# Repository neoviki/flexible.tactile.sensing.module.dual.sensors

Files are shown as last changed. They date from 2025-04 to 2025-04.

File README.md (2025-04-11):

# Flexible Tactile Sensing Module with Dual Sensors

## Description

This project features a **flexible tactile sensing module** equipped with **dual pressure sensors** designed to measure **tactile interaction**, specifically the pressure exerted by external forces. At the core of the module are two **BMP384 barometric pressure sensors** — MEMS (Micro-Electro-Mechanical Systems) sensors capable of measuring both **barometric pressure** and **temperature** with low power consumption. Their sensitivity makes them well-suited for tactile feedback and subtle pressure variation detection.

The **spacing between the two BMP384 sensors** is **3 millimeters**, allowing for localized differential pressure sensing. Both sensors communicate via the **I2C protocol**, ensuring straightforward integration with microcontroller boards such as the **Arduino Due**. The module operates at **3.3V**, and each sensor is assigned a unique I2C address to enable communication on the same bus:

- **Top Sensor**: `0x77`  
- **Bottom Sensor**: `0x76`

This tactile sensing module can be used in robotics, prosthetics, and human-machine interaction applications.

The **sensor module** is designed on a **flexible PCB**, making it adaptable to a wide range of environments where flexibility is essential. The design is created using **Eagle 7.7**, and the board is populated using **surface-mount technology (SMT)**. After population, the board has been tested with an **Arduino Due** to verify its sensor performance and sampling rate for tactile sensing applications.

## Project Structure

```
README.md
01.Documents                            # Essential documents used for this project
02.Schematics.and.Board.Layout.Design   # Contains the schematics and board layout files
03.Manufacturing                        # Contains CAM, DRU files, and other essential files for manufacturing
04.Populated.Board.Testing              # Contains Arduino code to test the tactile sensing module after population
05.Images                               # Contains a list of images
```

### Images

Here are some images related to the project, demonstrating the design and testing process:

1. **Populated Flexible Tactile Sensing Module**  
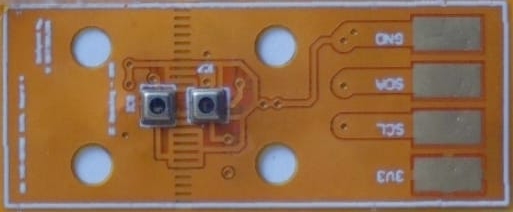
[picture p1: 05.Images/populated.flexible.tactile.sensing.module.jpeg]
Populated Flexible Tactile Sensing Module
   

2. **Board Layout**  
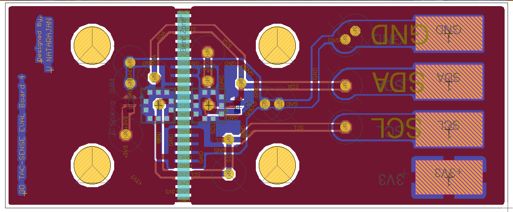
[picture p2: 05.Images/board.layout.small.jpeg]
Board Layout
   

3. **Schematics**  
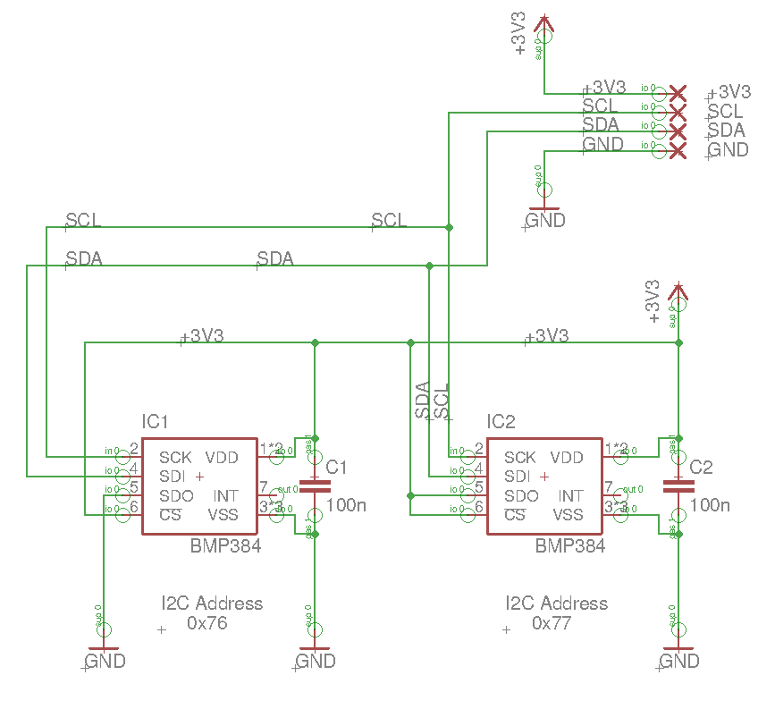
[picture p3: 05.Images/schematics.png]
Schematics
   

4. **Fabricated Flexible PCB**  
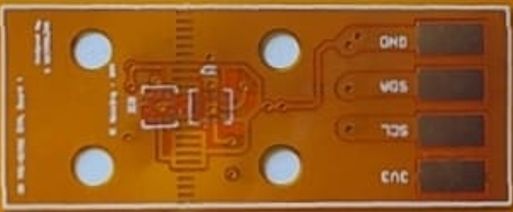
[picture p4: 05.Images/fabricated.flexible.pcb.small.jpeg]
Fabricated Flexible PCB
   

---

## License

This project is licensed under the **BSD 2-Clause License**.  
See the [`LICENSE`](LICENSE) file for full license text.

## Usage and Attribution

You are welcome to **use, modify, or build upon this design** for personal, academic, or commercial purposes.  
If you use or adapt any part of this work, **please credit the original author**:

**V. Natarajan**

For academic usage, you may cite this repository using the following BibTeX entry:

```bibtex
@misc{vnatarajan_flexible_tactile_sensing_module_dual_sensors,
  author       = {V. Natarajan},
  title        = {Flexible Tactile Sensing Module with Dual Sensors},
  year         = {2025},
  howpublished = {\url{https://github.com/neoviki/flexible.tactile.sensing.module.dual.sensors}},
  note         = {Accessed: 2025-04-11}

}
```

> 📎 Attribution helps support and recognize open-source contributions — thank you!

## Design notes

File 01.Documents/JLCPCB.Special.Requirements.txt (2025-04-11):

Please note that the stiffener area is defined in the `Stiffener_Bottom` layer. This layer includes drill holes that should be included in the stiffener material.

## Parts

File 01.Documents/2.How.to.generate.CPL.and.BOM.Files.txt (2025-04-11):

https://jlcpcb.com/help/article/82-How-to-generate-BOM-and-CPL-from-Eagle-CAD-automatically

Board Layout:
	1. File -> Run ULP
	2. Select File "jlcpcb_smta_exporter_v7.ulp"
	3. Select Top Layer -> Select a new folder -> Okay
	4. Again follow step 1 to 3 for bottom layer
	5. Both BOM and ULP will be generated

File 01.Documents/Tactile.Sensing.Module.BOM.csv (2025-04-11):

Part | Value | Device | Package | Description
C1 | 100n | C-EUC0201 | C0201 | CAPACITOR, European symbol
C2 | 100n | C-EUC0201 | C0201 | CAPACITOR, European symbol
I2C |  | PINHD-1X4/90 | 1X04/90 | PIN HEADER
IC1 | BMP384 | BMP384 | BMP384
IC2 | BMP384 | BMP384 | BMP384

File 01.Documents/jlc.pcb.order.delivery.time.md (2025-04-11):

Ordered after all comments 22 July 20XX
Delivery date August 1 20XX 
Time to Delivery from order = 10 days

Cheapest shipping with customs tax paid by JLC
[EuroPacket shipping service ]

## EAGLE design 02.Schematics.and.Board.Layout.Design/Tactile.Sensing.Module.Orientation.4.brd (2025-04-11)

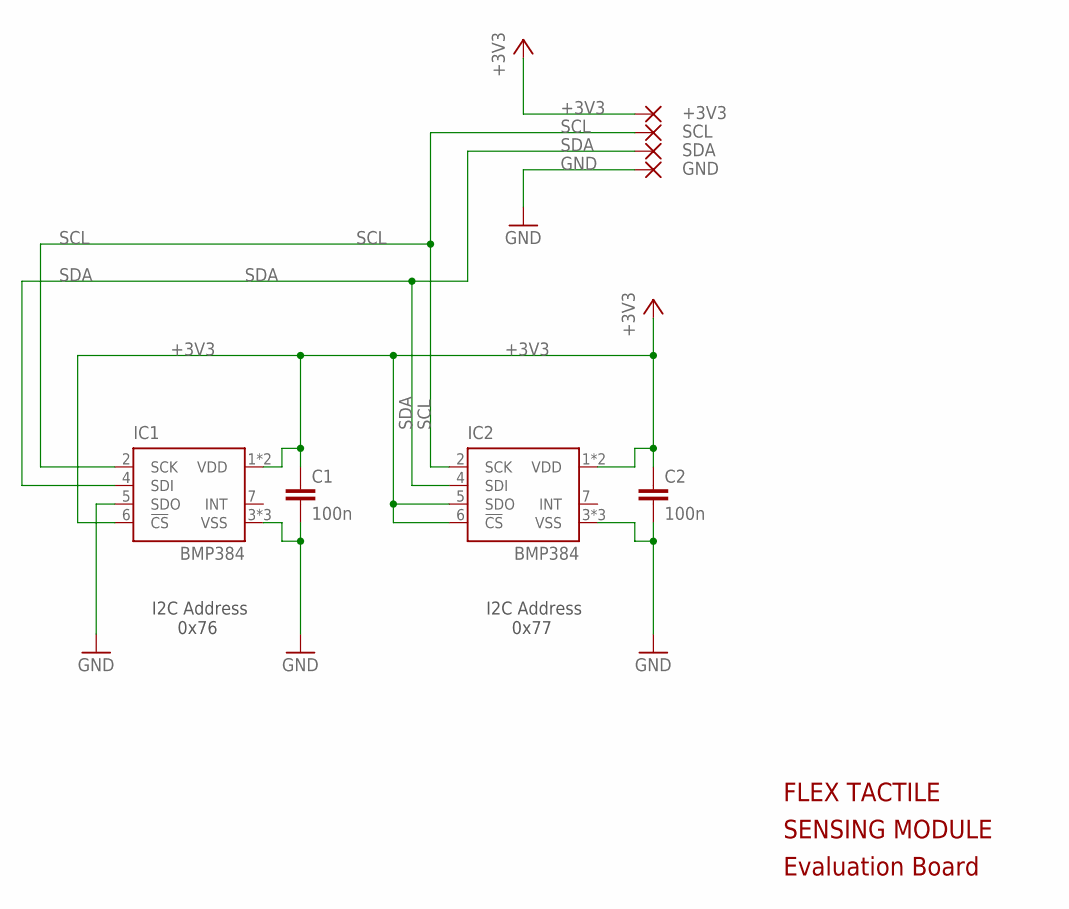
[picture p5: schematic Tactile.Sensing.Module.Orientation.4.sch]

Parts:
+3V3: SMD-PAD-2MMX4MM
C1, C2: 100n; C0201
GND: SMD-PAD-2MMX4MM
IC1, IC2: BMP384
SCL: SMD-PAD-2MMX4MM
SDA: SMD-PAD-2MMX4MM

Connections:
+3V3: +3V3.1, C1.1, C2.1, IC1.1 (VDD), IC1.6 (!CS), IC1.10 (VDD), IC2.1 (VDD), IC2.5 (SDO), IC2.6 (!CS), IC2.10 (VDD)
GND: C1.2, C2.2, GND.1, IC1.3 (VSS), IC1.5 (SDO), IC1.8 (VSS), IC1.9 (VSS), IC2.3 (VSS), IC2.8 (VSS), IC2.9 (VSS)
SCL: IC1.2 (SCK), IC2.2 (SCK), SCL.1
SDA: IC1.4 (SDI), IC2.4 (SDI), SDA.1

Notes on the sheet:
I2C Address 0x77
I2C Address 0x76
SENSING MODULE
Evaluation Board
FLEX TACTILE

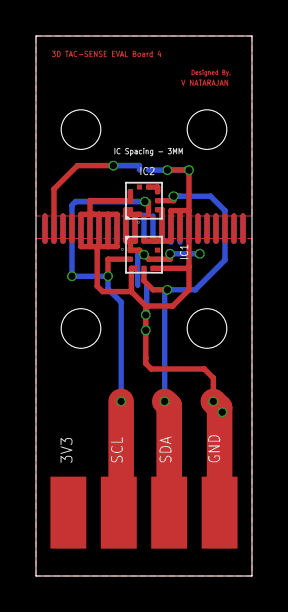
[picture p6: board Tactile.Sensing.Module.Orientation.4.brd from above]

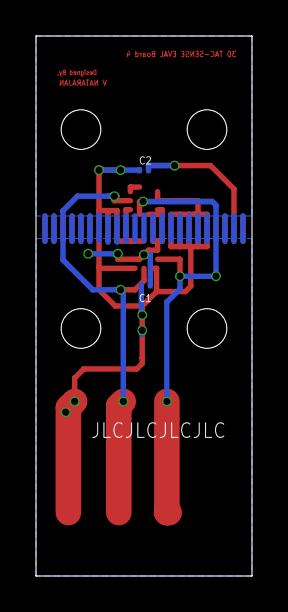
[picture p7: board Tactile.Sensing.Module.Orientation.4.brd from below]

Board: 2 copper layers, 12.0 x 30.0 mm, 8 parts (2 on the bottom side), 4 nets.

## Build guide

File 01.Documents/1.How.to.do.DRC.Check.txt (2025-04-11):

DRC -> load -> jlcpcb-2layers.dru

Check

it is typically done at the board layout

Also need to do the following to avoid stop mask error in DRC

DRC->Mask->limit
Limit: 0.004mm
Stop Min: 0.001mm
Stop Max: 0.004mm
% : 100

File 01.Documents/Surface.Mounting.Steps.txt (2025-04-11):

220 degrees, 13 percent air flow,

30 cm 60 sec
15 cm 30 sec
10 cm 30 sec
4 cm 30 sec
reverse the step, solder will be intact, circular motion

tin bot the componebnt and board

Solder paste I used:

	1. SN42BI58/T3 ( Mildly Rad-Active  - Carful while using )

I can see the same solder paster (1) in the market by EDSYN CR11 ( same SN42BI58 composition ), Melting temperature = 215 to 260 degrees, Wow. It cost 23.99 Euro in reichelt.de

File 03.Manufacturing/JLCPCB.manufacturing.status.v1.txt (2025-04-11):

Text is not visible

1. On Flex PCB, JCL is not able to print text smaller than 0.6096. Your text should be 0.6096 or bigger.
2. They forget to add stiffener
3. The fiber glass panel stiffener cutout is wrong

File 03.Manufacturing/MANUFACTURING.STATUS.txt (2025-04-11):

Manufactured the flex PCB, Populated the tactile sensing module and tested successfully.

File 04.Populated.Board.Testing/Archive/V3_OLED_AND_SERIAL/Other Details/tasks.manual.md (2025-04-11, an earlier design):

Arduino Search library u8g2 and install

- u8g2 by oliver

Tools -> Board -> Board Manager -> Install Arduino SAM Boards ( this is for Arduino Due )

Select Arduino Due Programming Port ( The usb port next to the DC Barrel Jack )

Tools -> Board -> Arm 32 Board -> Arduino Due Programming port

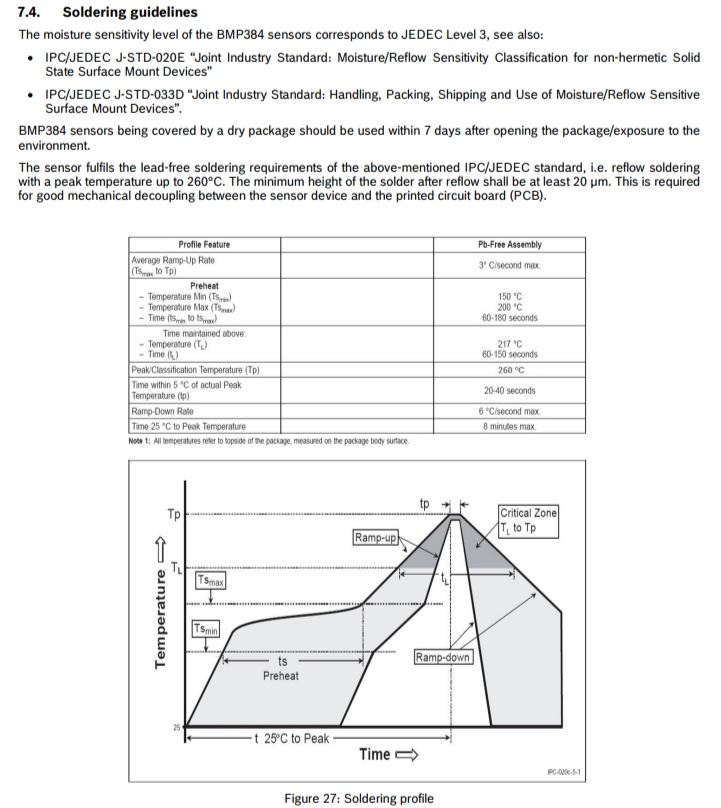
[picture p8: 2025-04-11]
01.Documents/BMP384.Soldering.Handy.Information/Soldering Temperature Profile 1.png

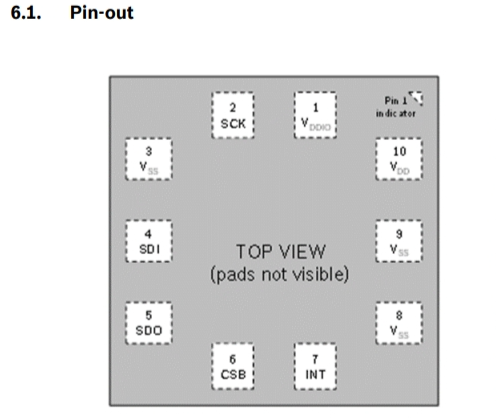
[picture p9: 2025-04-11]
01.Documents/BMP384.Soldering.Handy.Information/BMP384 Top View.png

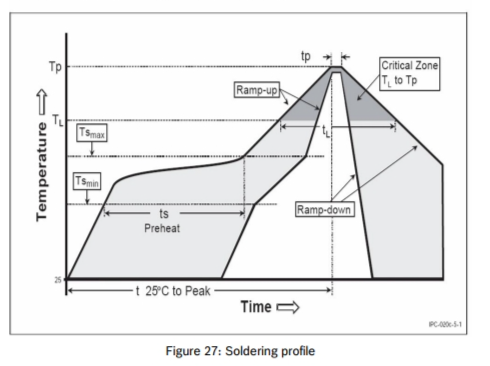
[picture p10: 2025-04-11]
01.Documents/BMP384.Soldering.Handy.Information/Soldering Temperature Profile 3.png

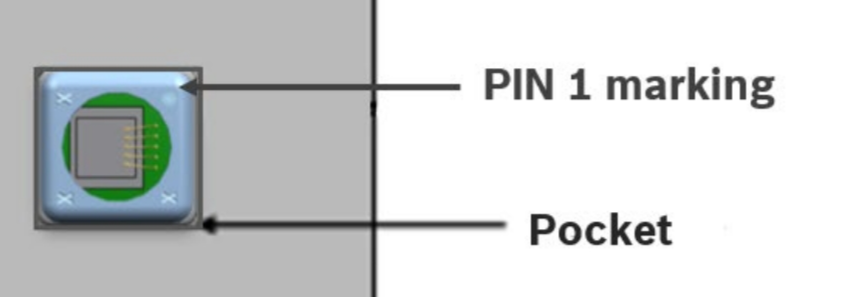
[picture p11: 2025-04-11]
01.Documents/BMP384.Soldering.Handy.Information/BMP384 Top View - Pin 1 Marking.png

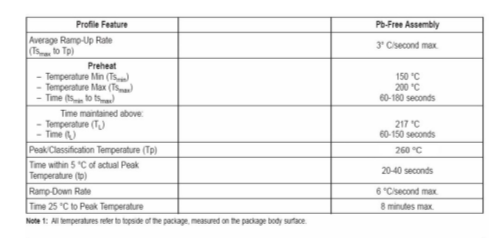
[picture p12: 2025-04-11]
01.Documents/BMP384.Soldering.Handy.Information/Soldering Temperature Profile 2.png

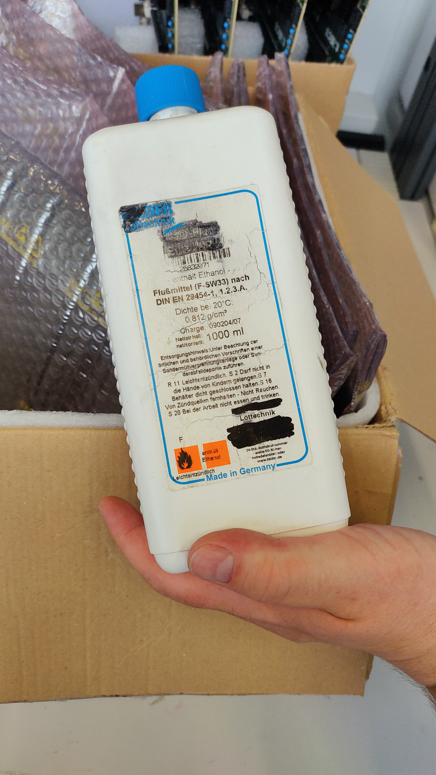
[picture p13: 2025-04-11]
01.Documents/Surface.Mounting.Equipments.Used.Images/solder flux liquid1.jpg

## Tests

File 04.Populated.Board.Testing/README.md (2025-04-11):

Arduino DUE is used to test the populated board. I made a custom board to test with OLED display. 
You can use the sketch/sketch.ino to test the populated board.

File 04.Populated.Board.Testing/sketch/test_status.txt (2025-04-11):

/*

Tested: the code works for my flex PCB on arduino Due

*/

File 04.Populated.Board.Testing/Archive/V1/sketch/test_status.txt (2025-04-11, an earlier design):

/*

Tested: the code works for my flex PCB on arduino Due

*/

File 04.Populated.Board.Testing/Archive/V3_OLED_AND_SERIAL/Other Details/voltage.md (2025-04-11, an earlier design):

MakerHawk I2C OLED Display Module I2C SSD1306 Tiny Screen Module 0.91 Inch, in White 128X32 I2C OLED Driver DC 3.3V to 5V for Arduino (Pack of 2)

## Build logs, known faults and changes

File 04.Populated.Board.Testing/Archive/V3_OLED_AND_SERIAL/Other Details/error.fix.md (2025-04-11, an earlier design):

if upload fails in arduino do the following

sudo groupadd dialout
sudo gpasswd -a $USER dialout
sudo usermod -a -G dialout $USER
reboot ( must - after reboot it works )

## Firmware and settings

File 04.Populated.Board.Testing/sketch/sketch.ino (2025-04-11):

/*

Tested with my prototype flex BMP Split PCB, It works perfect. 
Hardware used : Arduino DUE


Tested With BMP It is working perfect

*/
#include "oled_display_lib_bmp_test.h"
#include <Arduino.h>
#include <Wire.h>
#include "SparkFunBMP384.h"
#define PIN_WIRE_SDA         (20u)
#define PIN_WIRE_SCL         (21u)

BMP384 pressureSensor;

//BMP384_I2C_ADDRESS_DEFAULT; // 0x77

//BMP384_I2C_ADDRESS_SECONDARY; // 0x76



//IC1
#define IC1 0x76
#define IC2 0x77


/*IC on top of the PCB I designed*/
#define IC_TOP    IC2

/*IC on bottom of the PCB I designed*/
#define IC_BOTTOM IC1

void status_bmp_top(int s)
{
  if(s == 1){
      print_oled_sensor_top(1);
      Serial.println("BMP384 [TEST] [ TOP    ] [ PASS ]");    
  }else{
      print_oled_sensor_top(0);
      Serial.println("BMP384 [TEST] [ TOP    ] [ FAIL ]");
  }
}

void status_bmp_bottom(int s)
{
  if(s == 1){
      print_oled_sensor_bottom(1);
      Serial.println("BMP384 [TEST] [ BOTTOM ] [ PASS ]");

  }else{
      print_oled_sensor_bottom(0);
      Serial.println("BMP384 [TEST] [ BOTTOM ] [ FAIL ]");
  }
}


void test_bmp_top()
{
    int i;
    Wire.end();
    delay(300);
    Wire.begin();

    for(i=0;i<5;i++){
        if(pressureSensor.beginI2C(IC_TOP) != BMP3_OK){
          status_bmp_top(0);
        }else{
          status_bmp_top(1);	//SUCCESS
        }
        delay(100);
    }

    return;
}

void test_bmp_bottom()
{
    int i;
    Wire.end();
    delay(300);
    Wire.begin();

    for(i=0;i<5;i++){
        if(pressureSensor.beginI2C(IC_BOTTOM) != BMP3_OK){
            status_bmp_bottom(0);
        }else{
            status_bmp_bottom(1); //SUCCESS
        }
        delay(100);
    }

    return;
}

void setup()
{
    Serial.begin(115200);
    Serial.println("BMP384 I2C TESTER INIT");

    pinMode(21, OUTPUT);  
    
    for (int i = 0; i < 8; i++) {    
      digitalWrite(21, HIGH);    
      delayMicroseconds(3);    
      digitalWrite(21, LOW);    
      delayMicroseconds(3);  
    } 
    
    pinMode(21, INPUT);
    init_oled();
}

void loop()
{
	test_bmp_top();
	test_bmp_bottom(); 
}

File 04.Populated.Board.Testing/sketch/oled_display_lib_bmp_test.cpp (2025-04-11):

/*Works Perfect
  Board: Arduino Due
  Display: 0.91 inch display, see the images for reference

  just change DISPLAY_ON_I2C to I2C0 or I2C1 to choose different I2C

*/

#include "oled_display_lib_bmp_test.h"
#include <U8g2lib.h>

#define DISPLAY_HORIZANTAL U8G2_R0
#define DISPLAY_VERTICAL   U8G2_R1

#define I2C0 U8G2_SSD1306_128X32_UNIVISION_F_HW_I2C       /*SDA0, SCL0*/
#define I2C1 U8G2_SSD1306_128X32_UNIVISION_F_2ND_HW_I2C   /*SDA1, SCL1*/

//#define DISPLAY_ON_I2C I2C0
#define DISPLAY_ON_I2C I2C1

DISPLAY_ON_I2C u8g2(DISPLAY_HORIZANTAL);


void gotoxy(int x, int y , String text)
{
  u8g2.setFont( u8g2_font_helvB08_tr);
  u8g2.setCursor(x, y);
  u8g2.print(text);
  u8g2.sendBuffer();

}




void line1(String text)
{
  //gotoxy(5,12, text);
  gotoxy(25, 28, text);
  delay(100);
  clear_oled();
}

void line2(String text)
{
  //gotoxy(5,30, text);
  gotoxy(25, 28, text);
  delay(100);
  clear_oled();
}


void clear_oled()
{
  //u8g2.clearBuffer();
  //gotoxy(35, 28, "CLEAR");
  //delay(200);
  u8g2.clearBuffer();
  //gotoxy(20, 28, "TESTING");
  //delay(100);
  //u8g2.clearBuffer();

}

void print_oled_sensor_top(int s)
{
  if (s == 1) {
    line1("[ TOP ] -> [ PASS ]");
  } else {
    line1("[ TOP ] -> [ FAIL   ]");
  }

}

void print_oled_sensor_bottom(int s)
{
  if (s == 1) {
    line2("[ BOT ] -> [ PASS ]");
  } else {
    line2("[ BOT ] -> [ FAIL   ]");
  }

}


void init_oled()
{
  u8g2.begin();
}
